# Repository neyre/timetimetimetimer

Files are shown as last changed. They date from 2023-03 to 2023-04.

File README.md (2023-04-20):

A time timer with three time time timers.

# BOM & Hardware Notes
- [ESP32 MCU (1)](https://www.amazon.com/dp/B09XDMVS9N)
- [7-seg displays (3, sold in pack of 5)](https://www.amazon.com/dp/B07MCGDST2)
- [Encoder I bought (3, sold in pack of 5)](https://www.amazon.com/dp/B07F26CT6B)
- [Buzzer I bought (1, sold in pack of 5)](https://www.amazon.com/dp/B07MPYWVGD)

It's easiest to de-solder the headers from all of the boards (easy with a bit of solder wick) and solder wires to them. Some tape and zipties helps keep the many wires organized. I daisy-chained power and gnd across the displays and across the knobs to keep them tidier. Doing most of the soldering before installing it into the housing made it easiest.

Most stuff is held into the housing with M2 screws forced into the 3D printed plastic.

Wire the buzzer with its gnd & IO pins to ground, and the VCC pin to the digital output of the MCU. It buzzes when IO is pulled low, so this prevents it from buzzing until the MCU commands it.

The encoders are wired to 3.3V. The 7-seg displays are wired to 5V (an attempt to reduce the load on the voltage regulator on the ESP32 board). Everything is a common ground.

Yellow, red, white are probably the best display colors. Blue is hard to read up close with the white outlines.

This is powered off USB (from an old iPhone power brick), it'd need some optimization to be battery powered.

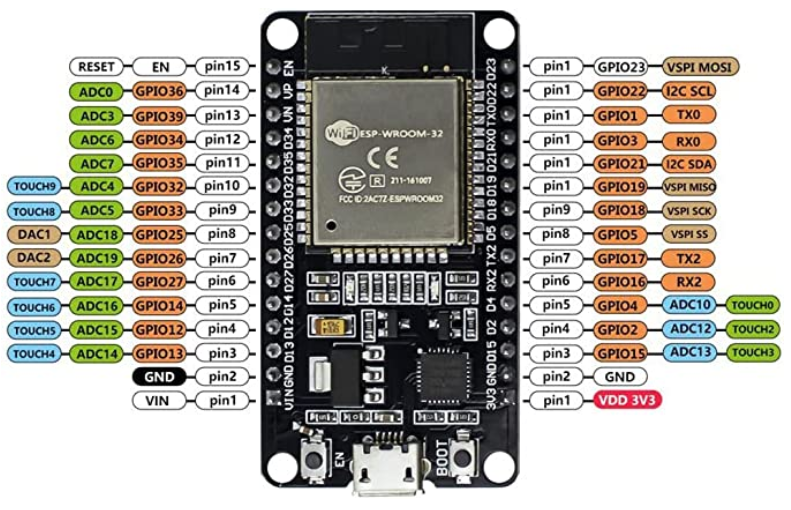
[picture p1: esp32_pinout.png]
pinout


# Useful Links
- [Rotary Encoder Library](https://github.com/miketeachman/micropython-rotary)
- [LED Driver Library](https://github.com/mcauser/micropython-tm1637)
- [Instructions for loading files with ampy](https://learn.adafruit.com/micropython-basics-load-files-and-run-code/file-operations)
- [Getting started guide with esp32 and micropython](https://docs.micropython.org/en/latest/esp32/tutorial/intro.html#esp32-intro)
- [Firmware downloads](https://micropython.org/download/esp32/) - this is using version esp32-20220618-v1.19.1.bin

# Misc. Notes

### Known Bugs
Pin 12 (knob #2) is linked to a pin that affects boot. Should move this to another pin as if this pin is high at boot, it doesn't boot right. Avoid pins 0/2/12/15

### Opportunities for performance improvement
- Right now, it's writing to the LEDs very frequently. Writing only when the value is different would probably speed things up.

### Misc. FW Notes
- enabling the watchdog creates problems when trying to push new firmware the watchdog resets it. 
- trying to put all the screen control logic in a second thread leads to noticable delay. just kept it all to one thread

# Command Reference

I don't use these commands often, so I'm including them here just so they're handy next time I need them. All are performed when connected to the ESP32 with USB.

##### To erase and install firmware

`esptool.py --port COM5 erase_flash`

`esptool.py --chip esp32 --port COM5 write_flash -z 0x1000 esp32-20220618-v1.19.1.bin`

##### To Run Code

`ampy -pCOM5 run main.py`

##### To Push Code

If code in a `main.py` file already running, stop it by connecting via serial and press Ctrl-A to stop code. Then run `ampy -pCOM5 rm main.py`

`ampy -pCOM5 put main.py`

Repeat for library files as required.

#### If Ampy Not Responding

First, make sure that the esp32 is booted correctly by opening the serial port with putty and making sure it's booted. See known issue about knob 2.

Then, see if the `main.py` needs to be stopped.

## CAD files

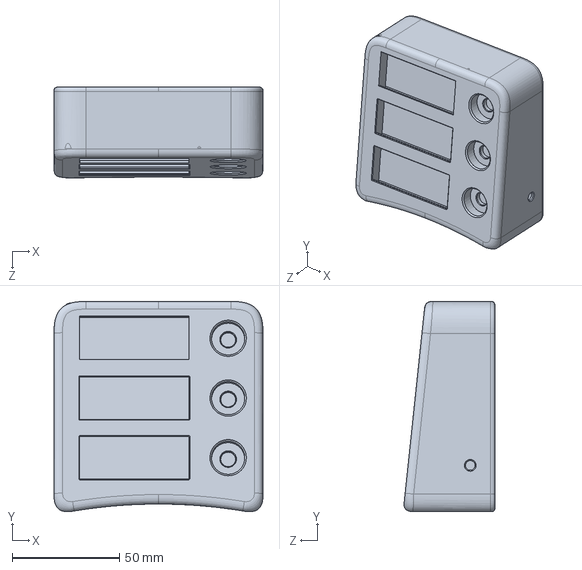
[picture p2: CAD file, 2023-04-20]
cad/P-9210_X1 Timer.SLDPRT
97.5 x 98.1 x 42.4 mm

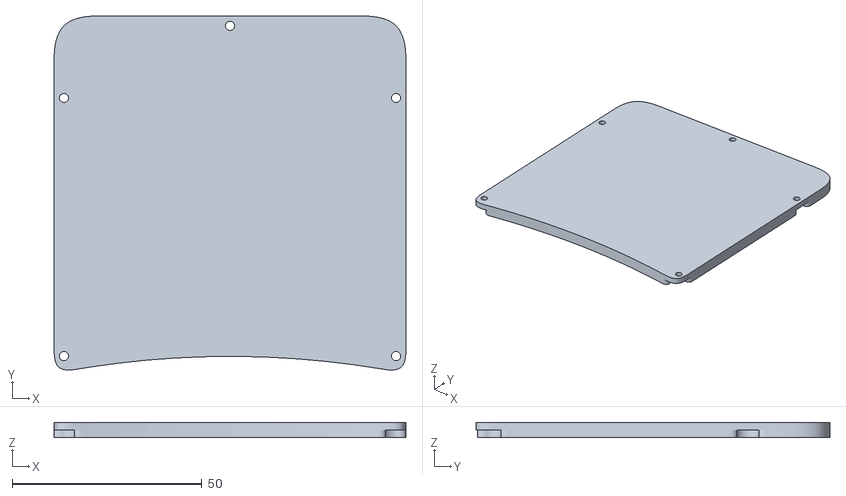
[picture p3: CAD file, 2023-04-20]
cad/P-9210_X1 Timer_cover.STL
92.7 x 93.3 x 4.00

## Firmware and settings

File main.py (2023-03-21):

import _thread
import esp32
import time
from machine import Pin, PWM, WDT, freq
from rotary_irq_esp import RotaryIRQ
import tm1637
import math

##########################
# Constants
##########################

buzzer_duration = 6
short_duration = 5.5 # Show seconds below this # of mins, must be < 60
knob_dwell = 3 # Stay in update mode for this long after an update

##########################
# Timer Controller Class
##########################

class TimeTimer(object):
    def __init__(self, screen_clk, screen_dio, enc_clk, enc_dio, brt, beep_pattern):

        # Setup Encoder
        self.enc = RotaryIRQ(pin_num_clk=enc_clk, pin_num_dt=enc_dio, min_val=0, half_step=True, reverse=False)
        
        # Setup Screen
        self.scr = tm1637.TM1637(clk=Pin(screen_clk), dio=Pin(screen_dio))
        self.scr.show('    ')
        self.scr.brightness(brt)

        # Expiration Time
        self.exp = 0    # End of Timer
        self.update_exp = 0   # End of Update Mode
        self.alarm_start = 0   # Alarm Start Time

        #  0 = Off
        # -1 = Screen Alarming
        #  1 = Running Counter
        self.status = 0

        self.beep_pattern = beep_pattern


    # Update and Display, Run Once per Loop
    def run(self):
        self.compute_time()

        # Time's Up - Transition to Alarming State
        if self.status == 1 and self.t <= 0:
            self.status = -1
            self.alarm_start = time.time()
            buz.on(self.beep_pattern)

        # State - Timer Running
        elif self.status == 1:
            self.display_time()

        # State - Timer Off
        elif self.status == 0:
            self.scr.show('    ')

        # State - Screen Alarming
        elif self.status == -1:
            self.display_alarm()

        self.handle_knob()

    # Compute time remaining
    def compute_time(self):
        # Compute Time Remaining
        self.t = self.exp - time.time()

        # Compute Hours, Minutes, Seconds
        self.h = math.floor(self.t/60/60)
        self.m = math.floor(self.t/60)%60 # Minutes Left
        self.m_disp = round(self.t/60)%60 # Rounded to Nearest Min, for seconds-free display
        self.m_total = math.floor(self.t/60) # Total Mins (e.g. 61 instead of 1:01)
        self.s = math.ceil(self.t%60)

        # Deal with special case of t=60 min
        if self.m_disp == 0 and self.h == 0 and self.t > 3000:
            self.h = 1

    # Format time and show it on the display
    def display_time(self):

        # Mode 1 - Short Duration, Show Seconds
        # Skip if in Update Window
        if self.update_exp-time.time() <= 0 and self.t < short_duration*60:
            self.scr.numbers(self.m_total, self.s)
        
        # Mode 2 - Medium Duration, Show Just Minutes
        elif self.h == 0:
            self.scr.number(self.m_disp)

        # Mode 3 - Long Duation, Show Hours and Minutes 
        else: 
            self.scr.numbers(self.h, self.m_disp)

    # Display Alarm Text (Food is Good)
    def display_alarm(self):
        elapsed = time.time() - self.alarm_start

        # Show Each Word for 2 Seconds
        if elapsed < 2:
            self.scr.write([113, 0b01011100, 0b01011100, 94])
        elif elapsed < 4:
            self.scr.show(' is ')
        elif elapsed < 6:
            self.scr.write([61, 0b01011100, 0b01011100, 94])
        else:
            self.status = 0

    # See if Knob has Changed, Update if So
    def handle_knob(self):
        
        # See which direction knob has moved
        k_new = self.enc.value()
        self.enc.reset()

        # Knob Turned Clockwise
        if k_new > 0:
            # Add minutes to timer
            if self.t <= 0:
                self.m_total = 0
            self.m_total += 1
            self.s = knob_dwell - 1

            # Turn off buzzer if alarming
            if self.status <1:
                self.status = 1
                buz.off()

        # Knob Turned Counterclockwise
        if k_new < 0:
            # Turn off if alarming
            if self.status < 1:
                self.status = 0
                buz.off()
                return

            # Pull minutes off timer
            if self.s <= knob_dwell:
                self.m_total -= 1
            self.s = knob_dwell - 1

        # Update timer and set into update mode
        if k_new != 0:
            t_new = self.m_total*60 + self.s
            if t_new <= 0:
                t_new = 0

            self.exp = time.time() + t_new
            self.update_exp = time.time() + knob_dwell


class BuzzerMinder(object):
    def __init__(self, pin_num):
        self.buzzer = Pin(pin_num, Pin.OUT)
        self.buzzer_end = 0
        self.pattern = 1

        # 0 = Buzzer Off
        # 1 = Buzzer On
        self.status = 0

    def run(self):

        # If Buzzer Expired, Transition to Off State
        if self.buzzer_end - time.time() <= 0:
            self.off()
            return

        # If Buzzer On
        if self.status == 1:

            # Beeping Pattern 1 - 70ms every 500ms
            if self.pattern == 1:
                period = time.ticks_ms() % 500
                if period <= 70:
                    self.buzzer.on();
                    return

            # Beeping Pattern 2 - 2x 50ms every 1000ms
            elif self.pattern == 2:
                period = time.ticks_ms() % 1000
                if ((period <= 50) or 
                    (period > 200 and period <= 250)):
                    self.buzzer.on();
                    return

            # Beeping Pattern 3 - 3x 50ms every 1000ms
            else:
                period = time.ticks_ms() % 1000
                if ((period <= 50) or 
                    (period > 150 and period <= 200) or
                    (period > 300 and period <= 350)):
                    self.buzzer.on();
                    return

        self.buzzer.off();

    def off(self):
        self.status = 0
        self.buzzer_end = 0
        self.buzzer.off();

    def on(self, beep_pattern):
        self.buzzer_end = time.time() + buzzer_duration
        self.status = 1
        self.pattern = beep_pattern


##########################
# Initialize Hardware and Objects
##########################

freq(80000000) # Underclock to 80MHz to save power, keep things cooler, why not
# watchdog = WDT(timeout=1000) # Skip it, causes trouble when loading new firmware
# esp32.wake_on_ext0(Pin(34), esp32.WAKEUP_ANY_HIGH)  # Waking from deep sleep on knob movement

t1 = TimeTimer(25, 33, 35, 34, 2, 1)
t2 = TimeTimer(26, 27, 14, 12, 3, 2)
t3 = TimeTimer(21, 19, 18, 5, 1, 3)
buz = BuzzerMinder(32)

# Display Power-On Message
t1.scr.show('11  ')
t2.scr.show(' 22 ')
t3.scr.show('  33')
time.sleep(1)
t1.scr.write([61, 0b01011100, 0b01011100, 94])
t2.scr.write([61, 0b01011100, 0b01011100, 94])
t3.scr.write([61, 0b01011100, 0b01011100, 94])
time.sleep(1)

##########################
# Main Loop
##########################

while True:
    t1.run()
    t2.run()
    t3.run()
    buz.run()

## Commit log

2023-03-11 Before adding threading for message
2023-03-11 remove threading for more predictable performance, add multiple beep patterns, everything working for now
2023-04-05 tidy up readme, add bom & hw notes, add license
2023-04-20 Add housing
    [P-9210_X1 Timer.SLDPRT, P-9210_X1 Timer_cover.STL]
